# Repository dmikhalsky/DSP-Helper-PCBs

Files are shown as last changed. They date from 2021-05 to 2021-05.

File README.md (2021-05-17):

Комбо-плата для различных DSP проектов на базе чипов AD.
На плате:
1. DC-DC 3.3в конвертер питания на базе микросхемы ADP3338 (используется в evalution board на базе ADAU1467, ультра-низкий коэффициент шума) + повышающий импульсный DC-DC  5в/12в конвертер для питания ОУ (универсальное посадочное место, например Mornsun A0512S-1WR3)
2. DC-DC LDO +12В/-12В на базе tps7A3001/tps7A4901 для малошумного питания ОУ после импульсного DC-DC
3. 2 платы ОУ на базе OPA2134 и фильтра 2-го порядка с MFB-топологией*
4. 2 платы ОУ на базе линейного драйвера DRV602/603 и фильтра 2-го порядка с MFB-топологией*
5. конвертер TOSLINK -> SPDIF на базе PLR135T

ВАЖНО: на данный момент проверены и работают части (1), (3) и (5)

В в папке Simulation находится файл для программы TINA-TI для расчета параметров фильтра и подбора номиналов

В папке "Individual PCBs" находятся схемы каждой подплаты и отдельные KiCAD-файлы. Эти KiCAD не протестированы и могут содержать ошибки.

**Рабочим является только комбо-файл в корневой папке**

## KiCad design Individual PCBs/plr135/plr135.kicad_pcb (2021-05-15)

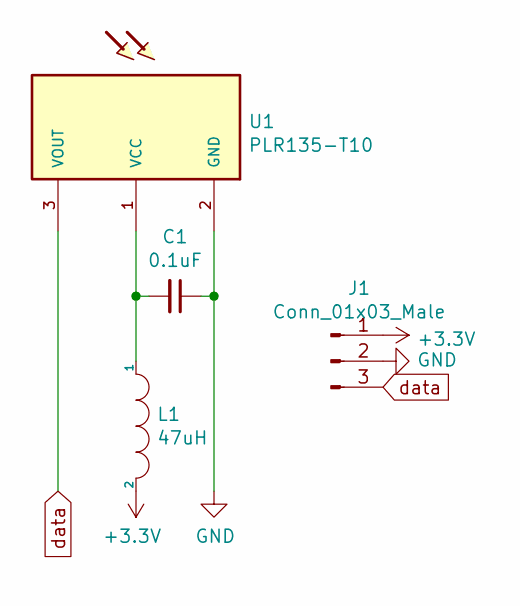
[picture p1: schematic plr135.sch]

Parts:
C1: 0.1uF; C_0805_HandSoldering
J1: Conn_01x03_Male; Pin_Header_Straight_1x03_Pitch2.54mm
L1: 47uH; L_0805_2012Metric_Pad1.05x1.20mm_HandSolder
U1: PLR135-T10; PLR135-T10_PLT133-T10W

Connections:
+3V3: J1.1, L1.2
GND: C1.1, J1.2, U1.2 (GND)
unnamed: C1.2, L1.1, U1.1 (VCC)
data: J1.3, U1.3 (VOUT)

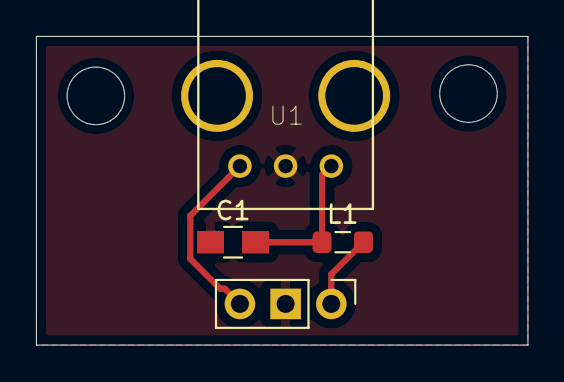
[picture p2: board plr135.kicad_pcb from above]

Board: 2 copper layers, 27.3 x 17.1 mm, 4 parts (0 on the bottom side), 4 nets.

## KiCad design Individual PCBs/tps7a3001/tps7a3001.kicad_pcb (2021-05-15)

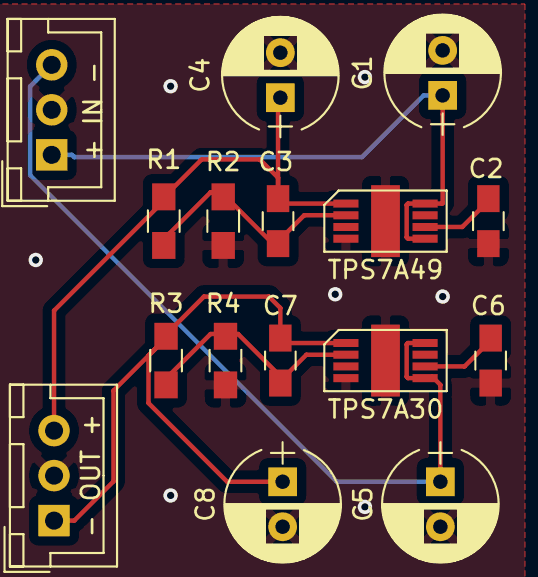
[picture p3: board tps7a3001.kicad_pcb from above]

Board: 2 copper layers, 16 parts (0 on the bottom side), 9 nets.

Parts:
+ IN -: Input; JST_XH_B03B-XH-A_03x2.50mm_Straight
- OUT +: Output; JST_XH_B03B-XH-A_03x2.50mm_Straight
C1, C4, C5, C8: 10uf; CP_Radial_D6.3mm_P2.50mm
C2, C6: 10nf; C_0805_HandSoldering
C3, C7: 10uf; C_0805_HandSoldering
R1, R2, R3, R4: R_Small; R_0805_HandSoldering
TPS7A30, TPS7A49: TPS7Axxx; TPS7Axx

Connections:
+12V: + IN -.1, C1.1, TPS7A49.5, TPS7A49.8
-12V: + IN -.3, C5.1, TPS7A30.5, TPS7A30.8
GND: + IN -.2, - OUT +.2, C1.2, C2.2, C4.2, C5.2, C6.2, C8.2, R2.2, R4.2, TPS7A30.4, TPS7A49.4
unnamed: C2.1, TPS7A49.6
unnamed: C3.2, R1.2, R2.1, TPS7A49.2
unnamed: C6.1, TPS7A30.6
unnamed: C7.2, R3.2, R4.1, TPS7A30.2
VCC: - OUT +.3, C3.1, C4.1, R1.1, TPS7A49.1
VEE: - OUT +.1, C7.1, C8.1, R3.1, TPS7A30.1

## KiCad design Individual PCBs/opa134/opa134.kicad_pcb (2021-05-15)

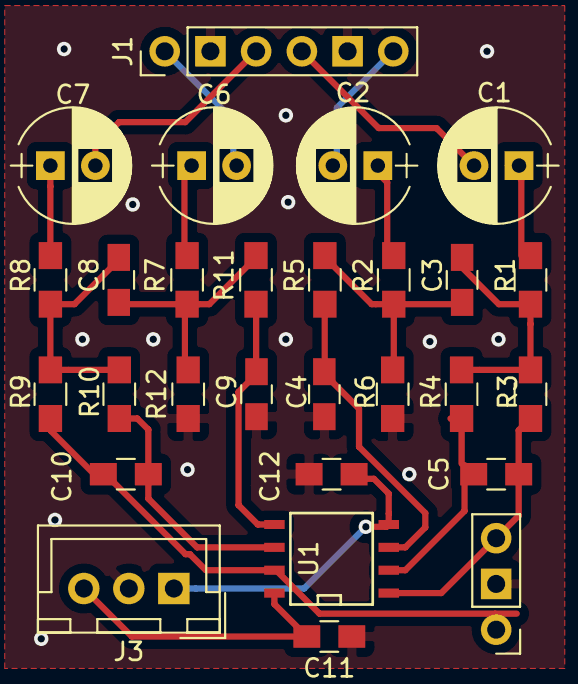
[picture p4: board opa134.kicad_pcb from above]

Board: 2 copper layers, 28 parts (0 on the bottom side), 21 nets.

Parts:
C1, C2, C6, C7: 10uf; CP_Radial_D6.3mm_P2.50mm
C3, C4, C8, C9: 10uf; C_0805_HandSoldering
C5, C10: 220pf; C_0805_HandSoldering
C11, C12: C_Small; C_0805_HandSoldering
J1: Input; Pin_Header_Straight_1x06_Pitch2.54mm
J3: Power; JST_XH_B03B-XH-A_03x2.50mm_Straight
J4: Otput; Pin_Header_Straight_1x03_Pitch2.54mm
R1, R2, R3, R4, R5, R6, R7, R8, R10, R11, R12: 22k; R_0805_HandSoldering
R9: 5k6; R_0805_HandSoldering
U1: OPA2134; SOIC-8-N

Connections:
+12V: C11.2, J3.3, U1.8
-12V: C12.2, J3.1, U1.4
/AmpL+: C4.1, R5.1, U1.3
/AmpL-: C5.1, R4.1, U1.2
/AmpL_out: C5.2, J4.3, R3.2, U1.1
/AmpR+: C9.1, R11.2, U1.5
/AmpR-: C10.1, R10.2, U1.6
/AmpR_out: C10.2, J4.1, R9.2, U1.7
/INL+: C2.2, J1.6
/INL-: C1.2, J1.4
/INR+: C6.2, J1.1
/INR-: C7.2, J1.3
GND: C4.2, C9.2, C11.1, C12.1, J1.2, J1.5, J3.2, J4.2, R6.1, R12.1
unnamed: C1.1, R1.2
unnamed: C2.1, R2.2
unnamed: C3.1, R1.1, R3.1, R4.2
unnamed: C3.2, R2.1, R5.2, R6.2
unnamed: C6.1, R7.2
unnamed: C7.1, R8.2
unnamed: C8.1, R8.1, R9.1, R10.1
unnamed: C8.2, R7.1, R11.1, R12.2

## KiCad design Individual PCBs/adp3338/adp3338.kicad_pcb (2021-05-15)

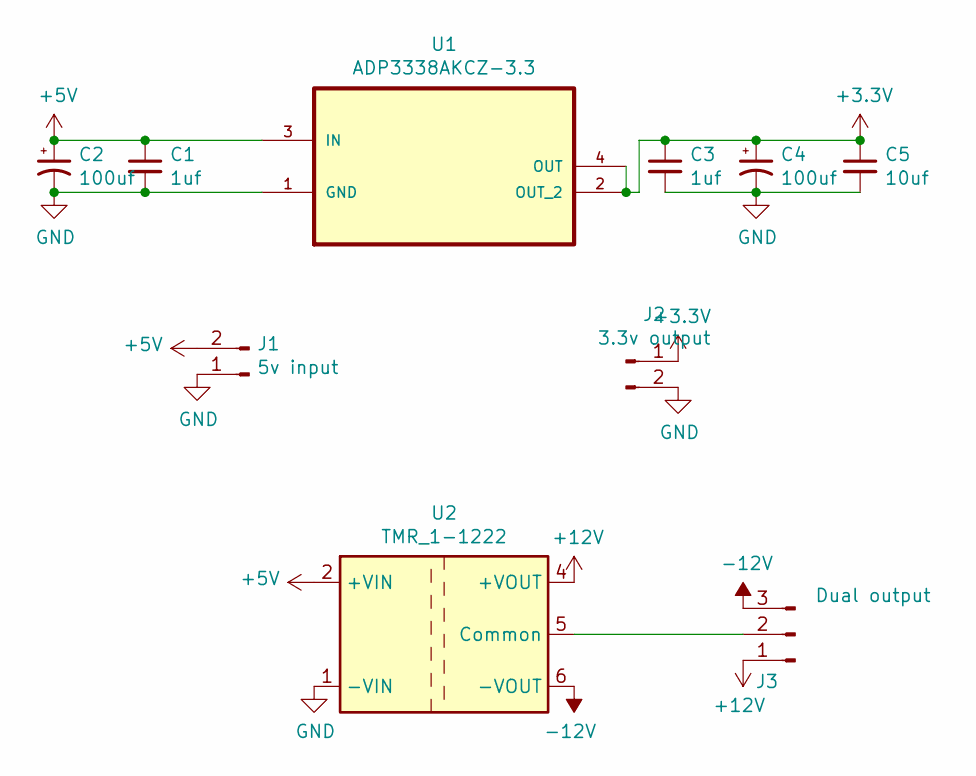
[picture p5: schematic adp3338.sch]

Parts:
C1, C3: 1uf; C_0805_HandSoldering
C2, C4: 100uf; CP_Radial_D6.3mm_P2.50mm
C5: 10uf; C_0805_HandSoldering
J1: 5v input; JST_XH_B02B-XH-A_02x2.50mm_Straight
J2: 3.3v output; JST_XH_B02B-XH-A_02x2.50mm_Straight
J3: Dual output; JST_XH_B03B-XH-A_03x2.50mm_Straight
U1: ADP3338AKCZ-3.3; SOT230P700X180-4N; MPN ADP3338AKCZ-3.3
U2: TMR_1-1222; TMH0512D

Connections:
+3V3: C3.1, C4.1, C5.1, J2.1, U1.2 (OUT_2), U1.4 (OUT)
+5V: C1.1, C2.1, J1.2, U1.3 (IN), U2.2 (+VIN)
+12V: J3.1, U2.4 (+VOUT)
-12V: J3.3, U2.6 (-VOUT)
GND: C1.2, C2.2, C3.2, C4.2, C5.2, J1.1, J2.2, U1.1 (GND), U2.1 (-VIN)
unnamed: J3.2, U2.5 (Common)

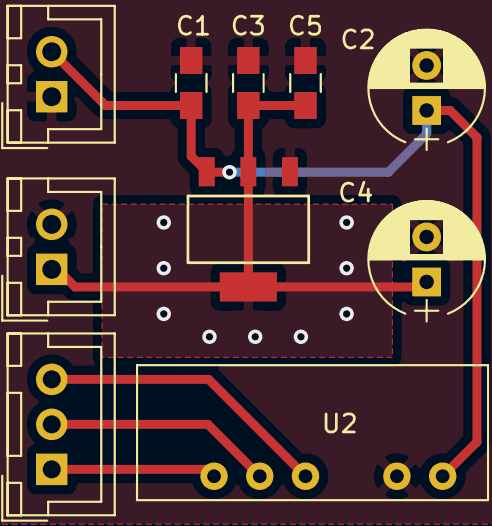
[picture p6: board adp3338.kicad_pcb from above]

Board: 2 copper layers, 10 parts (0 on the bottom side), 6 nets.

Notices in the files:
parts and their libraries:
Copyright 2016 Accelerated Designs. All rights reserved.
